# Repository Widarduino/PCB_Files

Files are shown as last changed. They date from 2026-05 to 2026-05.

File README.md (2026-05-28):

## [Variable Buck Converter(WIP)](./Buck/)

This project involved creating a buck converter which could regulate a 10V power supply to voltage suitable for a breadboard. simulations were done in LTspice and KiCad was used for creating schematics and PCB Layout.

### PCB Revision #1
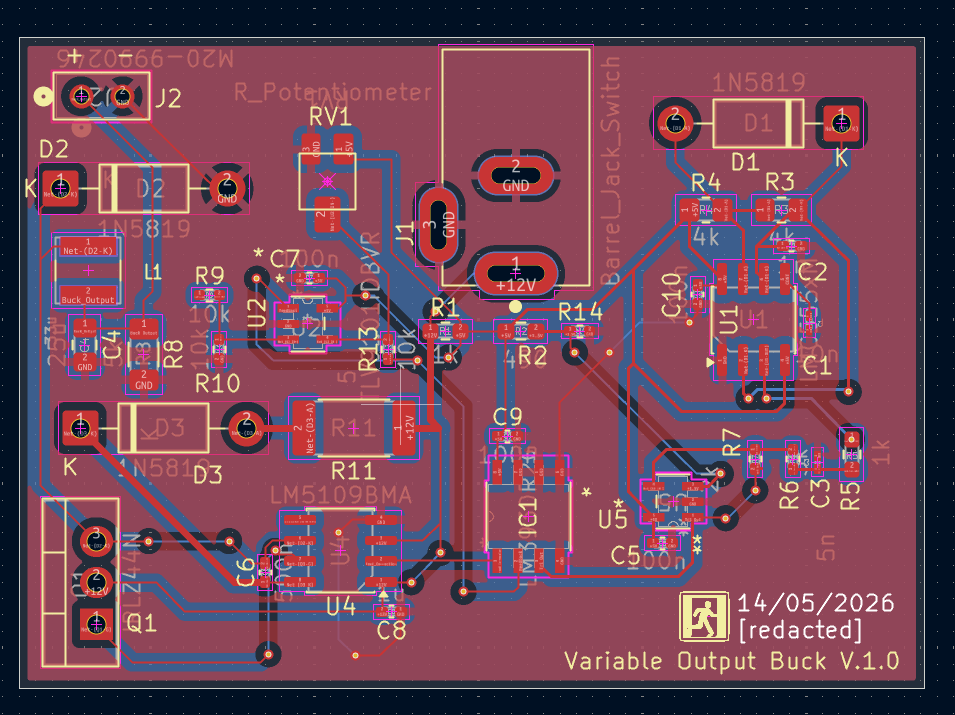
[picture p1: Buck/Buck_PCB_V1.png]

Currently awaiting second revision, due to high currents causing gate driver IC to fry
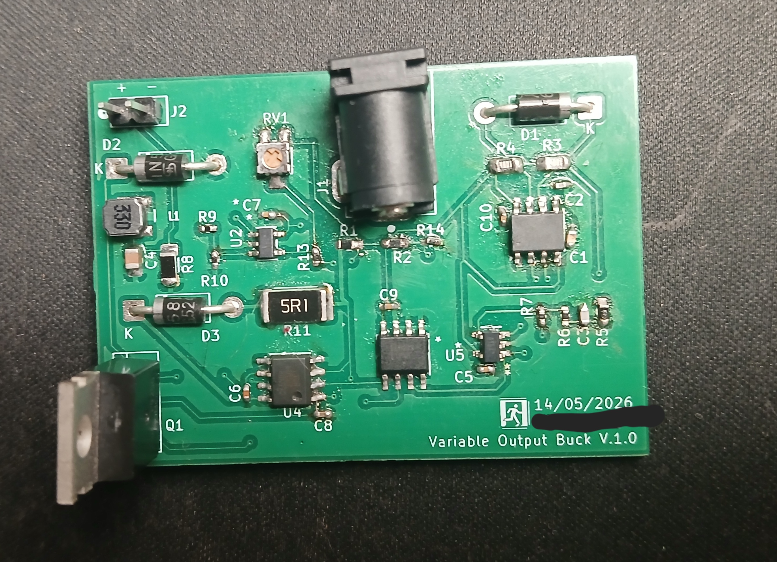
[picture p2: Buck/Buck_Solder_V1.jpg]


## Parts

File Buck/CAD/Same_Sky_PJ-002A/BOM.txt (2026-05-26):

3DX_Same_Sky_Supplier: Same Sky
3DX_Same_Sky_Description: 2.0 x 6.5 mm, 2.5 A, Horizontal, Through Hole, Dc Power Jack Connector
3DX_Same_Sky_Model Number: PJ-002A

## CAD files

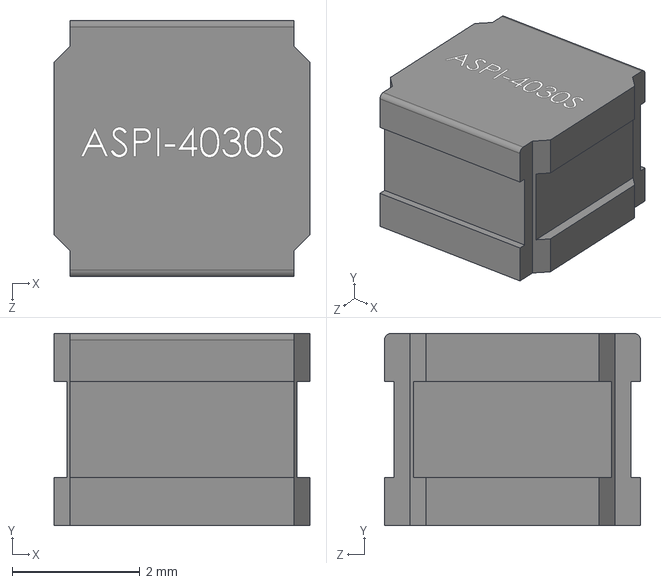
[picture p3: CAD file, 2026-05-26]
Buck/CAD/inductor33u/ASPI_4030S_330M_T/ASPI-4030S-330M-T.step
4.00 x 3.00 x 4.00 mm

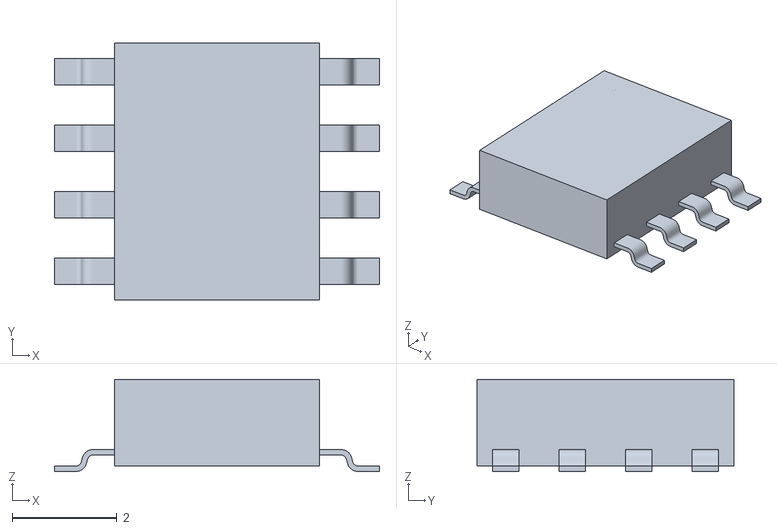
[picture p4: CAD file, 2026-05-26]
Buck/CAD/LM393(onsemi)/LM393DR2G/SOIC8_ONS.stl
6.20 x 4.90 x 1.75

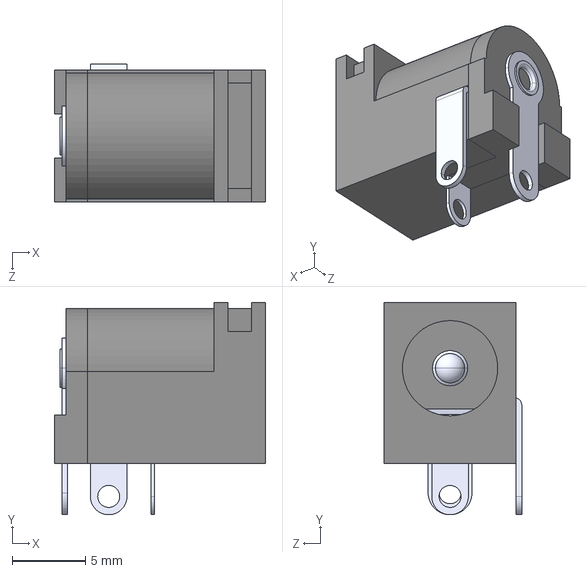
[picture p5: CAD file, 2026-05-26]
Buck/CAD/PJ_002A(1)/PJ-002A.step
14.4 x 14.5 x 9.40 mm

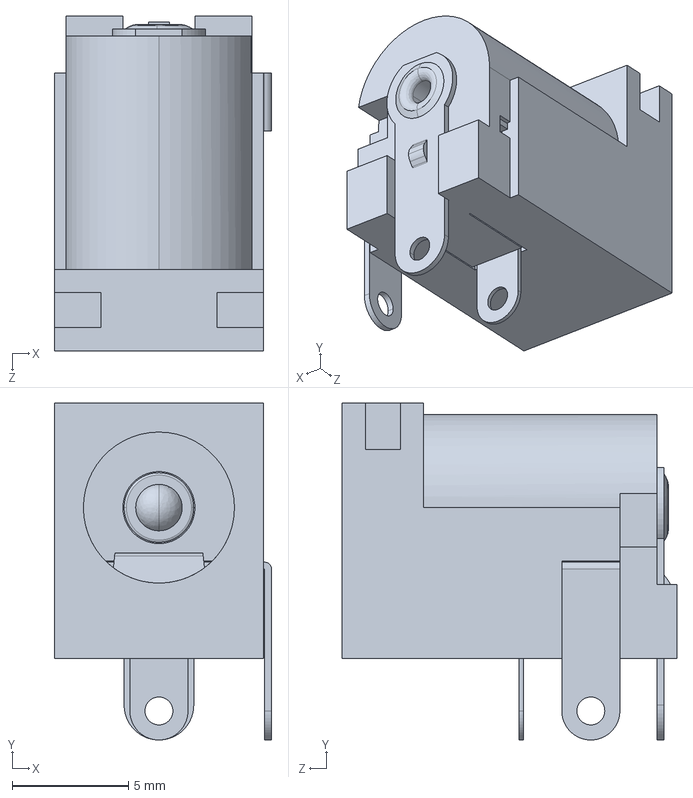
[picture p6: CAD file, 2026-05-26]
Buck/CAD/Same_Sky_PJ-002A/Same_Sky_PJ-002A.step
9.35 x 14.5 x 14.4 mm

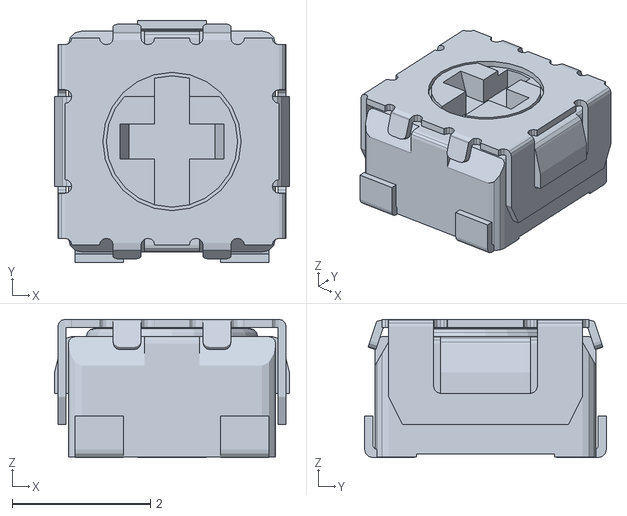
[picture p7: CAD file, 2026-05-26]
Buck/CAD/st-32A/COPAL_ST32ETA200k25/ST-32ETA200k_(25).stl
3.40 x 3.50 x 2.00

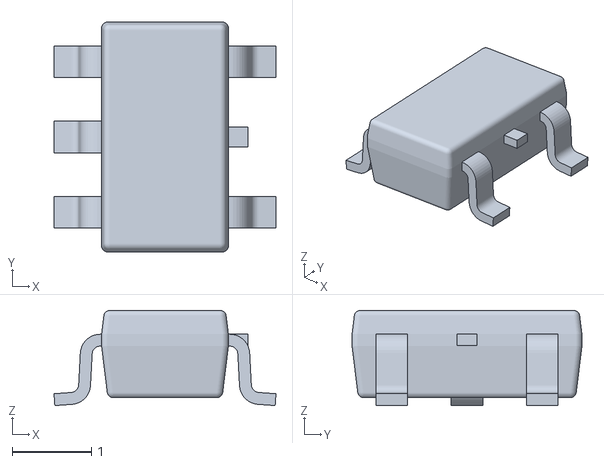
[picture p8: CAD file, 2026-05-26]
Buck/CAD/TLV/TLV9101IDBVR/DBV0005A.stl
2.80 x 2.90 x 1.20

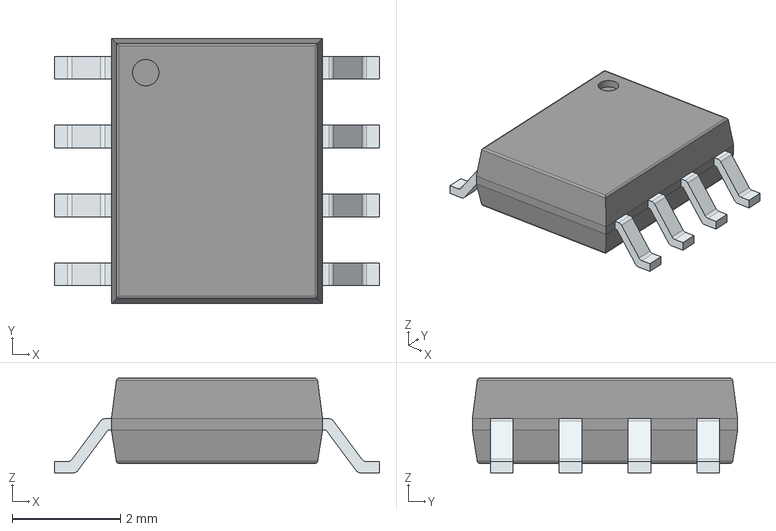
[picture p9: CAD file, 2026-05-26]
Kicad imports/LIB_LM393DR2G/LM393DR2G/3D/LM393DR2G.stp
6.00 x 4.90 x 1.75 mm
PinsArrayLR

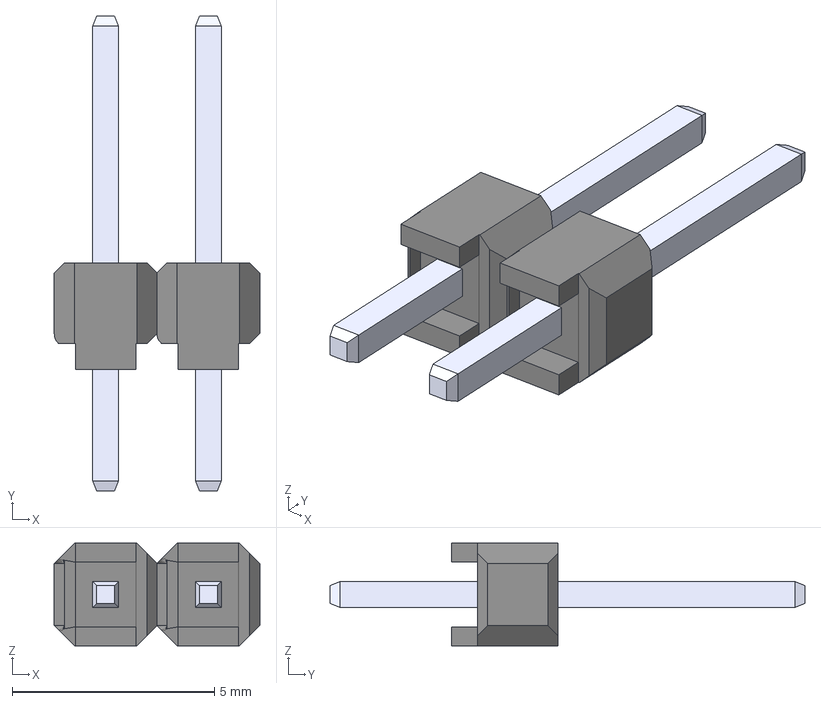
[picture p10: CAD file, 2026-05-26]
Buck/CAD/2pinheader/M20_9990246/M20-9990246.step
5.08 x 11.7 x 2.54 mm

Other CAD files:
Kicad imports/LM393DR2G/SOIC8_ONS.step
Kicad imports/TLV9101IDBVR/DBV0005A.stp
Buck/CAD/st-32A/COPAL_ST32ETA200k25(2)/ST-32ETA200k_(25).stp
Kicad imports/LIB_LM393DR2G/LM393DR2G/Allegro/soic127p600x175-8n.psm
Kicad imports/LIB_LM393DR2G/LM393DR2G/DEHDL/lm393dr2g/chips/chips.prt

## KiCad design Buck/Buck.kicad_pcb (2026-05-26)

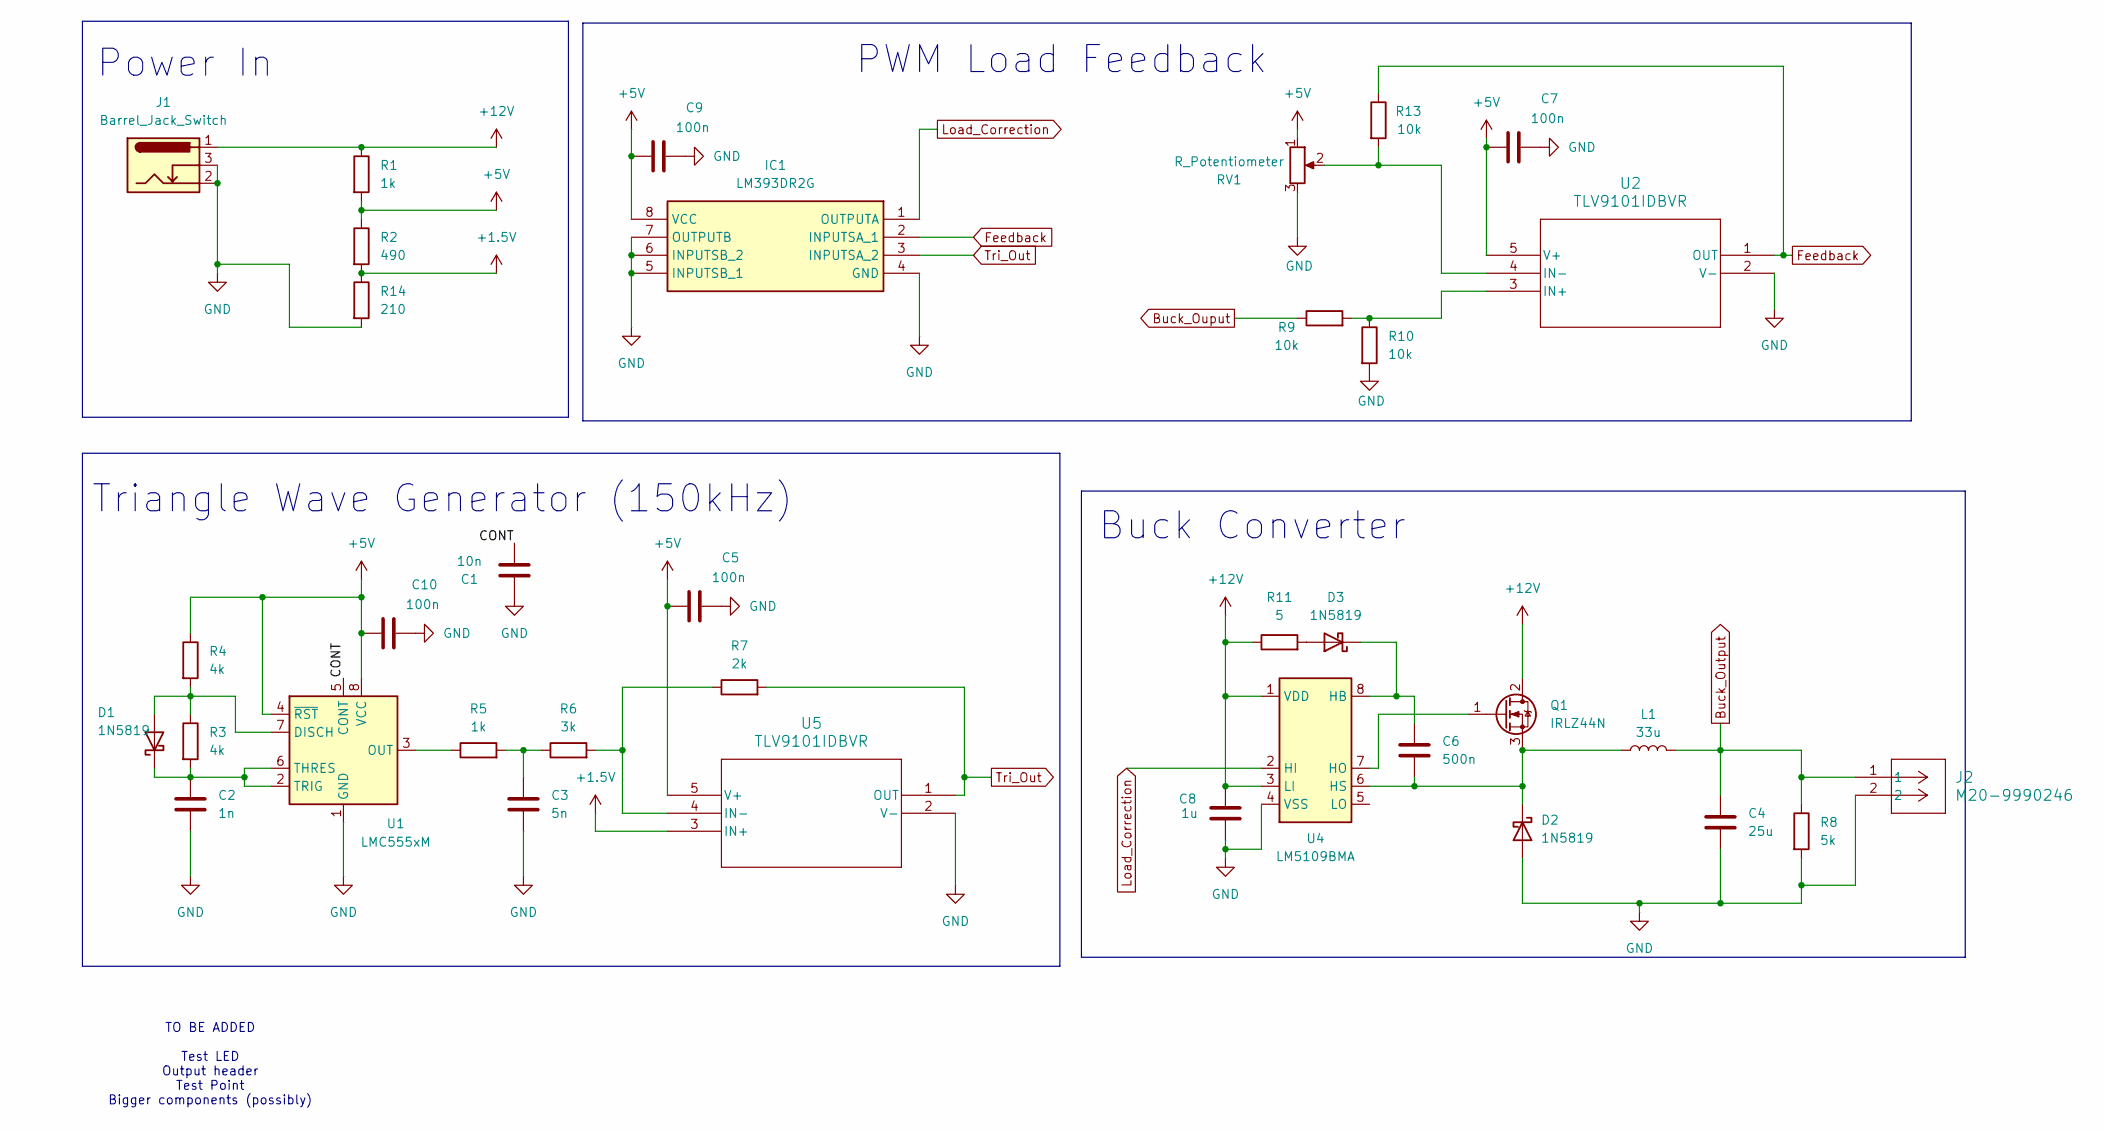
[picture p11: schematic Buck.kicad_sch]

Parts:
C1: 10n; C_0201_0603Metric_Pad0.64x0.40mm_HandSolder
C2: 1n; C_0402_1005Metric_Pad0.74x0.62mm_HandSolder
C3: 5n; C_0201_0603Metric_Pad0.64x0.40mm_HandSolder
C4: 25u; C_0805_2012Metric_Pad1.18x1.45mm_HandSolder
C5, C7, C9, C10: 100n; C_0402_1005Metric_Pad0.74x0.62mm_HandSolder
C6: 500n; C_0402_1005Metric_Pad0.74x0.62mm_HandSolder
C8: 1u; C_0402_1005Metric_Pad0.74x0.62mm_HandSolder
D1, D2, D3: 1N5819; D_DO-41_SOD81_P10.16mm_Horizontal
IC1: LM393DR2G; SOIC8_ONS; Manufacturer_Part_Number LM393DR2G; Mouser Part Number 863-LM393DR2G
J1: Barrel_Jack_Switch; CUI_PJ-002A
J2: M20-9990246; CONN2_M20-999_1x2_HRW
L1: 33u; IND_ASPI-4030S-330M-T
Q1: IRLZ44N; TO-220-3_Vertical
R1, R5: 1k; R_0603_1608Metric_Pad0.98x0.95mm_HandSolder
R2: 490; R_0603_1608Metric_Pad0.98x0.95mm_HandSolder
R3, R4: 4k; R_0805_2012Metric_Pad1.20x1.40mm_HandSolder
R6: 3k; R_0402_1005Metric_Pad0.72x0.64mm_HandSolder
R7: 2k; R_0402_1005Metric_Pad0.72x0.64mm_HandSolder
R8: 5k; R_1206_3216Metric_Pad1.30x1.75mm_HandSolder
R9, R10, R13: 10k; R_0402_1005Metric_Pad0.72x0.64mm_HandSolder
R11: 5; R_2512_6332Metric_Pad1.40x3.35mm_HandSolder
R14: 210; R_0402_1005Metric_Pad0.72x0.64mm_HandSolder
RV1: R_Potentiometer; ST-32
U1: LMC555xM; SOIC-8_3.9x4.9mm_P1.27mm
U2, U5: TLV9101IDBVR; DBV0005A_TEX
U4: LM5109BMA; SOIC-8_3.9x4.9mm_P1.27mm

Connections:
+1.5V: R2.2, R14.1, U5.3 (IN+)
+5V: C5.1, C7.1, C9.1, C10.1, IC1.8 (VCC), R1.2, R2.1, R4.1, RV1.1, U1.4 (~RST), U1.8 (VCC), U2.5 (V+), U5.5 (V+)
+12V: C8.2, J1.1, Q1.2 (D), R1.1, R11.1, U4.1 (VDD), U4.3 (LI)
/CONT: C1.1, U1.5 (CONT)
Buck_Ouput: R9.1
Buck_Output: C4.1, J2.1, L1.2, R8.1
Feedback: IC1.2 (INPUTSA_1), R13.1, U2.1 (OUT)
GND: C1.2, C2.2, C3.2, C4.2, C5.2, C7.2, C8.1, C9.2, C10.2, D2.2 (A), IC1.4 (GND), IC1.5 (INPUTSB_1), IC1.6 (INPUTSB_2), IC1.7 (OUTPUTB), J1.2, J1.3, J2.2, R8.2, R10.2, R14.2, RV1.3, U1.1 (GND), U2.2 (V-), U4.4 (VSS), U5.2 (V-)
Load_Correction: IC1.1 (OUTPUTA), U4.2 (HI)
unnamed: C3.1, R5.2, R6.1
unnamed: D1.2 (A), R3.1, R4.2, U1.7 (DISCH)
unnamed: C2.1, D1.1 (K), R3.2, U1.2 (TRIG), U1.6 (THRES)
unnamed: C6.2, D2.1 (K), L1.1, Q1.3 (S), U4.6 (HS)
unnamed: D3.2 (A), R11.2
unnamed: C6.1, D3.1 (K), U4.8 (HB)
unnamed: Q1.1 (G), U4.7 (HO)
unnamed: R5.1, U1.3 (OUT)
unnamed: R9.2, R10.1, U2.3 (IN+)
unnamed: R13.2, RV1.2, U2.4 (IN-)
unnamed: R6.2, R7.1, U5.4 (IN-)
Tri_Out: IC1.3 (INPUTSA_2), R7.2, U5.1 (OUT)

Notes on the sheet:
Triangle Wave Generator (150kHz)
Buck Converter
PWM Load Feedback
TO BE ADDED Test LED Output header Test Point Bigger components (possibly)
Power In

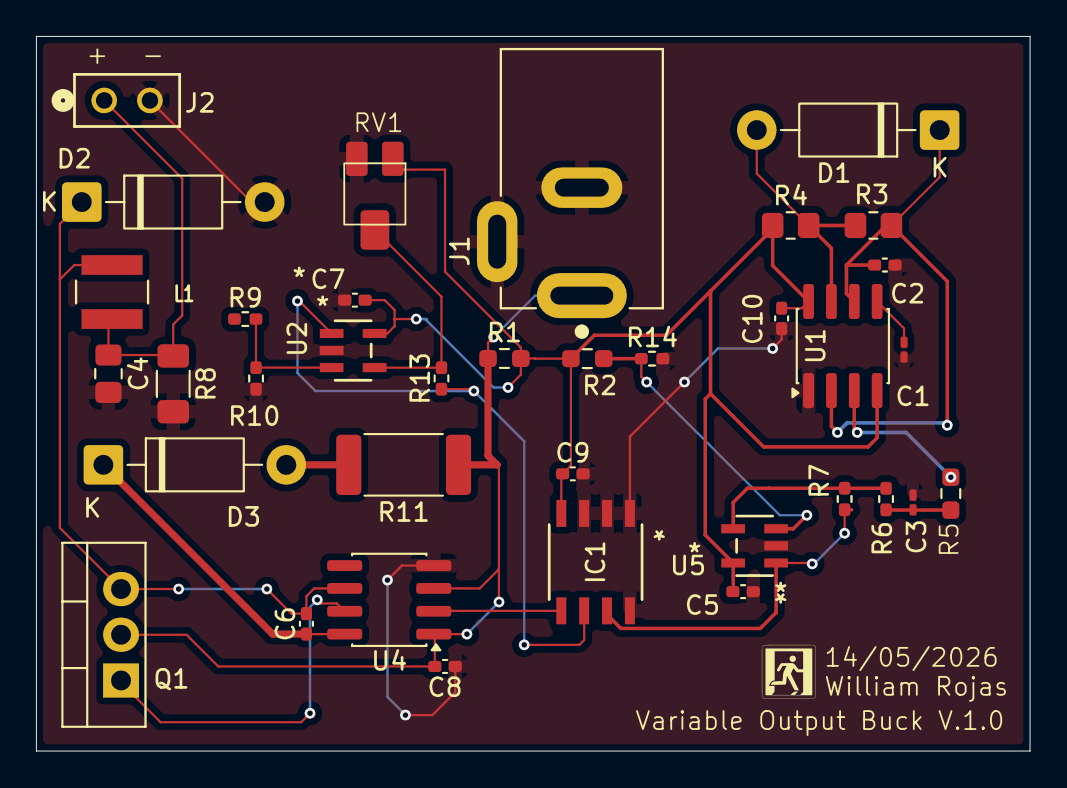
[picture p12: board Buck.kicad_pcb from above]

Board: 2 copper layers, 55.2 x 39.7 mm, 36 parts (0 on the bottom side), 20 nets.
